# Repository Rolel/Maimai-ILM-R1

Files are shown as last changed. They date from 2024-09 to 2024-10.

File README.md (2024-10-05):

# Maimai LED - ILM-R1 remake

Remake of the ILM-R1 PCB used for lighting in Maimai arcade cabinet. This is not a 1:1 reproduction but a fully compatible and same light intensity as the original.

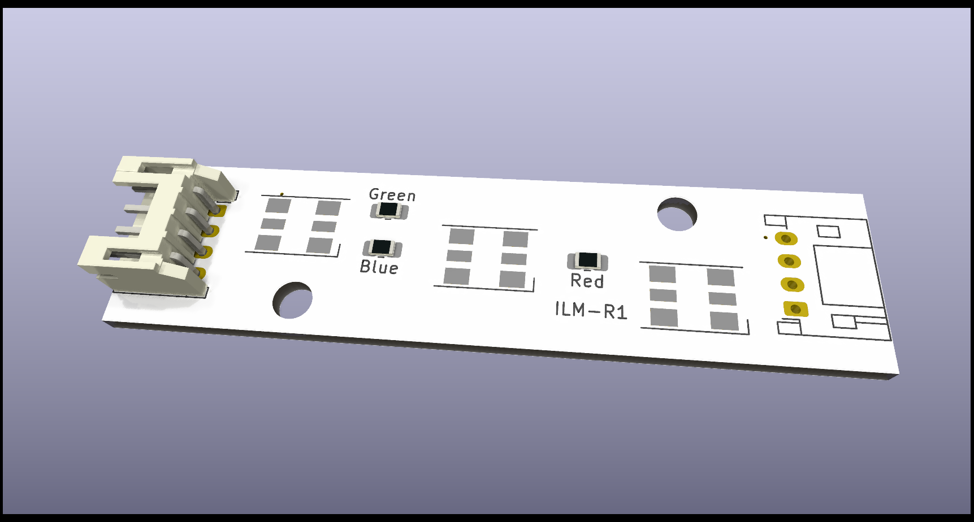
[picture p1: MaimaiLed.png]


## BOM

* Inolux IN-P55TATRGB RGB leds (manufacturer ref: IN-P55TATRGB )
* 0805 resistors
  * Red: 450 ohms
  * Green: 130 ohms
  * Blue: 150 ohms
  
The resistors values have a some tolerance, even on original boards the value differs. 

## PCB

Kicad files are made with version 8. 

They can be produced at PCBway. Upload the `MaimaiLed.kicad_pcb.zip` file into the "Quick Order" tool, then keep default settings, that's all.

Even simpler, have a look at the published project.

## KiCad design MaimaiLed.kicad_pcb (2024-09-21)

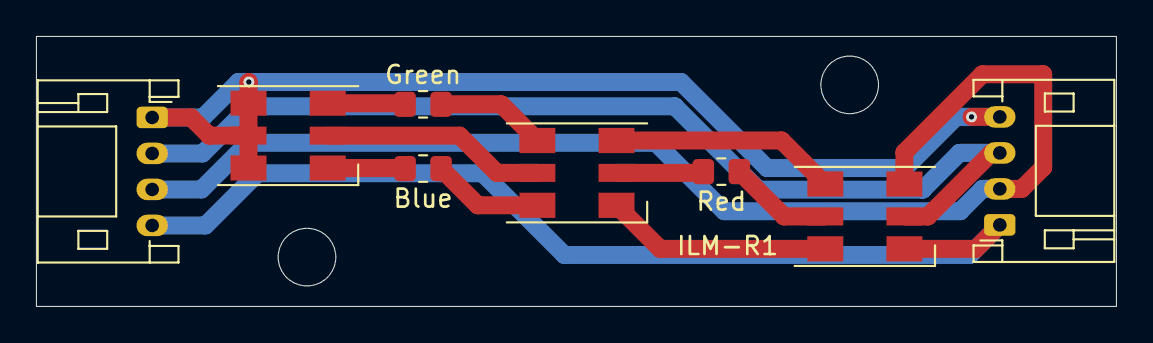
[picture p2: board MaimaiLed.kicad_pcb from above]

Board: 2 copper layers, 60.0 x 15.0 mm, 10 parts (0 on the bottom side), 13 nets.

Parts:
Blue: 150; R_0805_2012Metric_Pad1.20x1.40mm_HandSolder
D1, D2, D3: Inolux_IN-P55TATRGB; LED_Inolux_IN-P55TATRGB_PLCC6_5.0x5.5mm_P1.8mm
Green: 130; R_0805_2012Metric_Pad1.20x1.40mm_HandSolder
H1, H2: MountingHole; MountingHole_3.2mm_M3
J1: ConnLeft; JST_PH_S4B-PH-K_1x04_P2.00mm_Horizontal
J2: ConnRightNP; JST_PH_S4B-PH-K_1x04_P2.00mm_Horizontal
Red: 450; R_0805_2012Metric_Pad1.20x1.40mm_HandSolder

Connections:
unnamed: D1.4 (AG), D1.5 (AR), D1.6 (AB), J1.1, J2.4
unnamed: Blue.2, D1.1 (KB)
unnamed: D1.3 (KG), Green.1
unnamed: D1.2 (KR), D2.5 (AR)
unnamed: Blue.1, D2.6 (AB)
unnamed: D2.4 (AG), Green.2
unnamed: D2.1 (KB), D3.6 (AB)
unnamed: D2.3 (KG), D3.4 (AG)
unnamed: D2.2 (KR), Red.2
unnamed: D3.5 (AR), Red.1
unnamed: D3.1 (KB), J1.4, J2.1
unnamed: D3.3 (KG), J1.3, J2.2
unnamed: D3.2 (KR), J1.2, J2.3

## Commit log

2024-09-21 Add Kicad files
    [MaimaiLed.kicad_pcb, MaimaiLed.kicad_sch]
2024-10-05 Updated Readme and project schematic
    [MaimaiLed.kicad_sch]
